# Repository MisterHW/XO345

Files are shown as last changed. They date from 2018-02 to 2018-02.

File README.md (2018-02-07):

# XO345
is a drop-in replacement for FT245 that eliminates USB in favor of a single SPI slave interface - making USB peripherals embedded peripherals without USB host and device driver. Initially developed on a MachXO2-7000HE board (hence XO245), then ported and tested with MachXO3L-1300E and MachXO3LF-6900C (renamed to XO345).

In its final implementation, a WLCSP MachXO3-1300E sits on a QFP-32 sized PCB with castellations and directly connects to the former FT245 pads. Its crystal is removed and additional signals are routed out on these pins.

PCB files will be uploaded here as well, for now please check out https://hackaday.io/project/9547-xo245

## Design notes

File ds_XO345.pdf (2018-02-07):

# XO345 SPI-Parallel Interface

FT245BL pin compatible interface controller to use USB-enabled devices with SPI

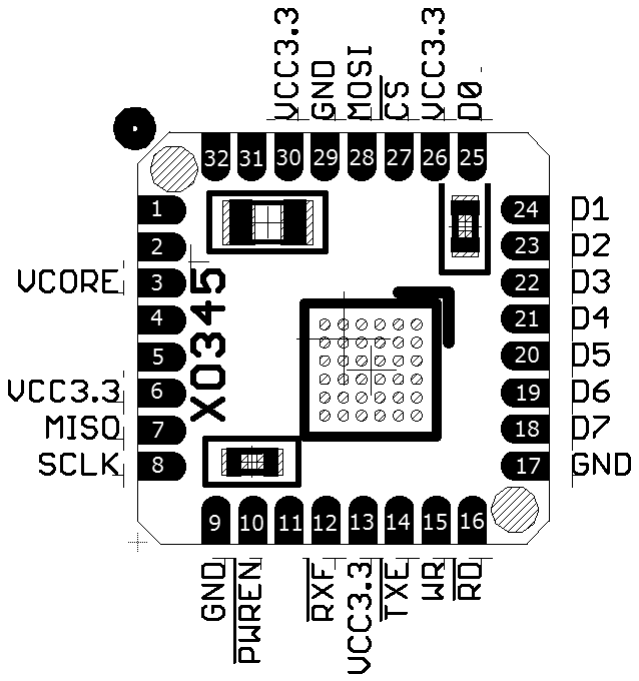
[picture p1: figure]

Features:

-QFP-32 0.8mm form factor
-drop-in replacement for FT245BL device
- on-board bypass caps
- multiple 3.3V pads
- SPI and VCORE 1.2V routed to D+,D-,XIN,XOUT and VUSB pads
- no bulky programming header
- 4-wire SPI Mode 0
up to 33 MHz
- EEPROM and control pins
connected (dev option)
- deep 256 Byte RX and
256 Byte TX buffers
- low power consumption

Description:

The XO345 is an FPGA-based FIFO interface hybrid designed as a drop-in replacement for the FTDI FT245BL chip. It has a „245“ compatible parallel interface to the target board side and provides a 4-wire MODE 0 MSB-First slave SPI as an external interface.
SPI signals and VCORE are routed to easily accessible USB and XTAL pins. While VCCIO 3.3V is supplied via pad 13, only VCORE 1.2V needs to be supplied via the existing 5V VUSB line (USB powered implementation). SPI signals are 3.3V.
Transmit and Receive buffers are 256 Byte wide, read and write timings are within 25ns of the original specs and compliant.

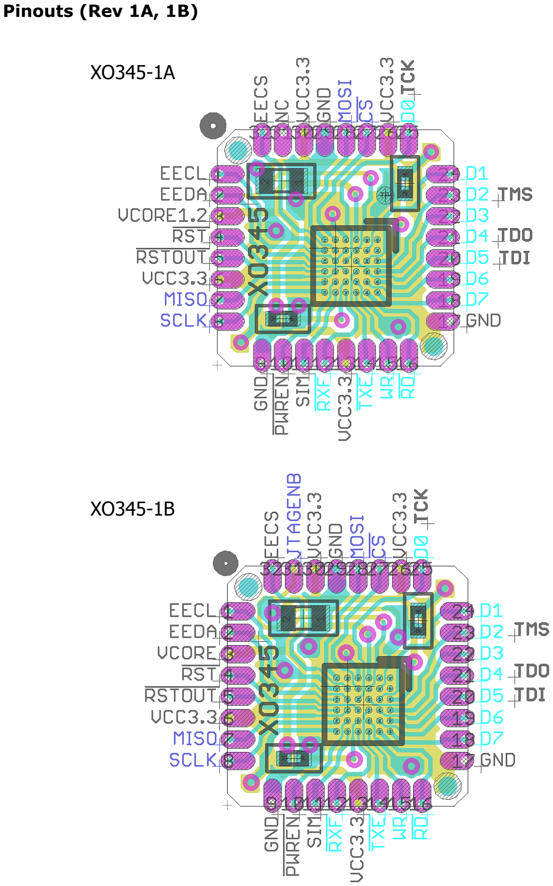
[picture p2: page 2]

Pinouts (Rev 1A, 1B)

XO345-1A

XO345-1B

Command Set

!PWREN flag [default: disabled (high)]

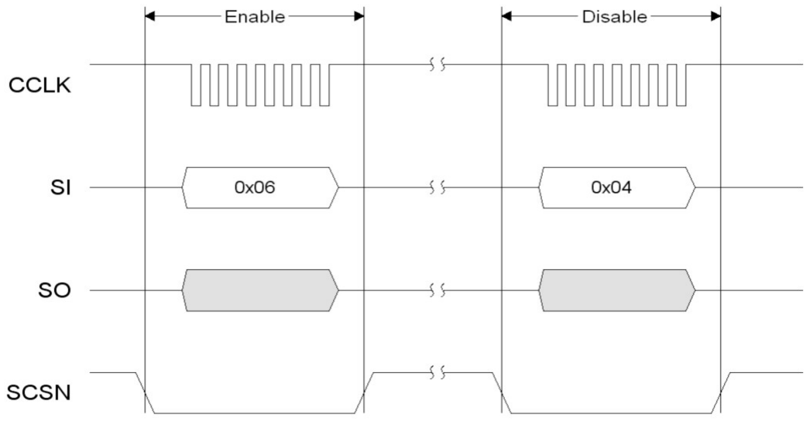
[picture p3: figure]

GPO_0 control register [default: 0x00]

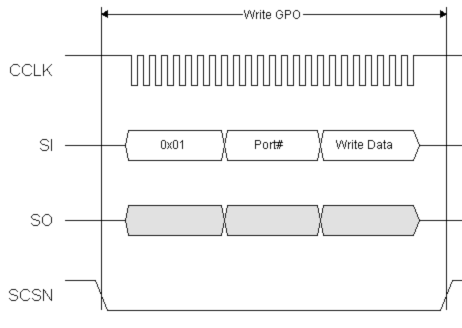
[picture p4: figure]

7 | 6 | 5 | 4 | 3 | 2 | 1 | 0
Reserved | Reserved | Reserved | Reserved | Reserved | Reserved | RXFN_STATE | RXFN_MODE

RXFN_MODE: when 0, !RXF is inhibited during write actions to the RX buffer. This simulates the bundling of bytes in a USB frame. After the write action !RXF is controlled by the level of the RX FIFO and the reaction to RDN pulses.

RXFN_STATE: (RXFN_STATE, RXFN_MODE) = 11: !RFX permanently inhibited, 01: !RXF immediately derived from the FIFO fill level and response to !RD pulses, x0: no effect

GPI_0 FIFO status register [default: 0x33]

Port#= 0x00

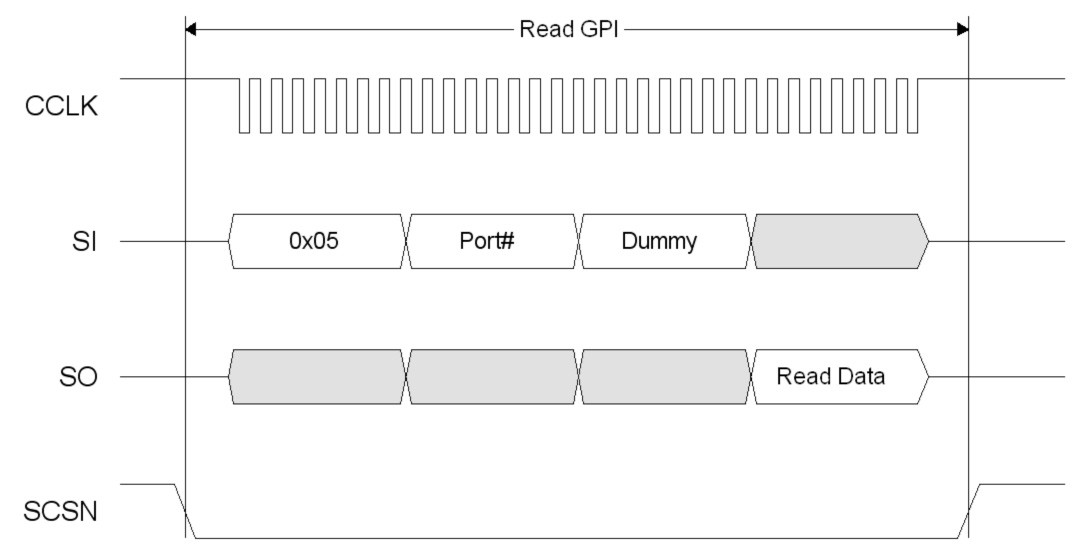
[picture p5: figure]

7 | 6 | 5 | 4 | 3 | 2 | 1 | 0
RX_FULL | RX_HI | RX_LO | RX_EMPTY | TX_FULL | TX_HI | TX_LO | TX_EMPTY

RX_FULL: RX FIFO is full at 256 Bytes (no more Bytes can be written)

RX_HI: RX FIFO is almost full (>=240 Bytes)

RX_LO: RX FIFO is not significantly filled (<= 16 Bytes)

RX_EMPTY: RX FIFO is completely empty at 0 Bytes

RX_FULL: TX FIFO is full at 256 Bytes (no more Bytes can be written)

RX_HI: TX FIFO is almost full (>=240 Bytes)

RX_LO: TX FIFO is not significantly filled (<= 16 Bytes)

RX_EMPTY: TX FIFO is completely empty at 0 Bytes

GPI_1 status register [reserved]

Port#= 0x01

7 | 6 | 5 | 4 | 3 | 2 | 1 | 0
Reserved | Reserved | Reserved | Reserved | Reserved | Reserved | Reserved | Reserved

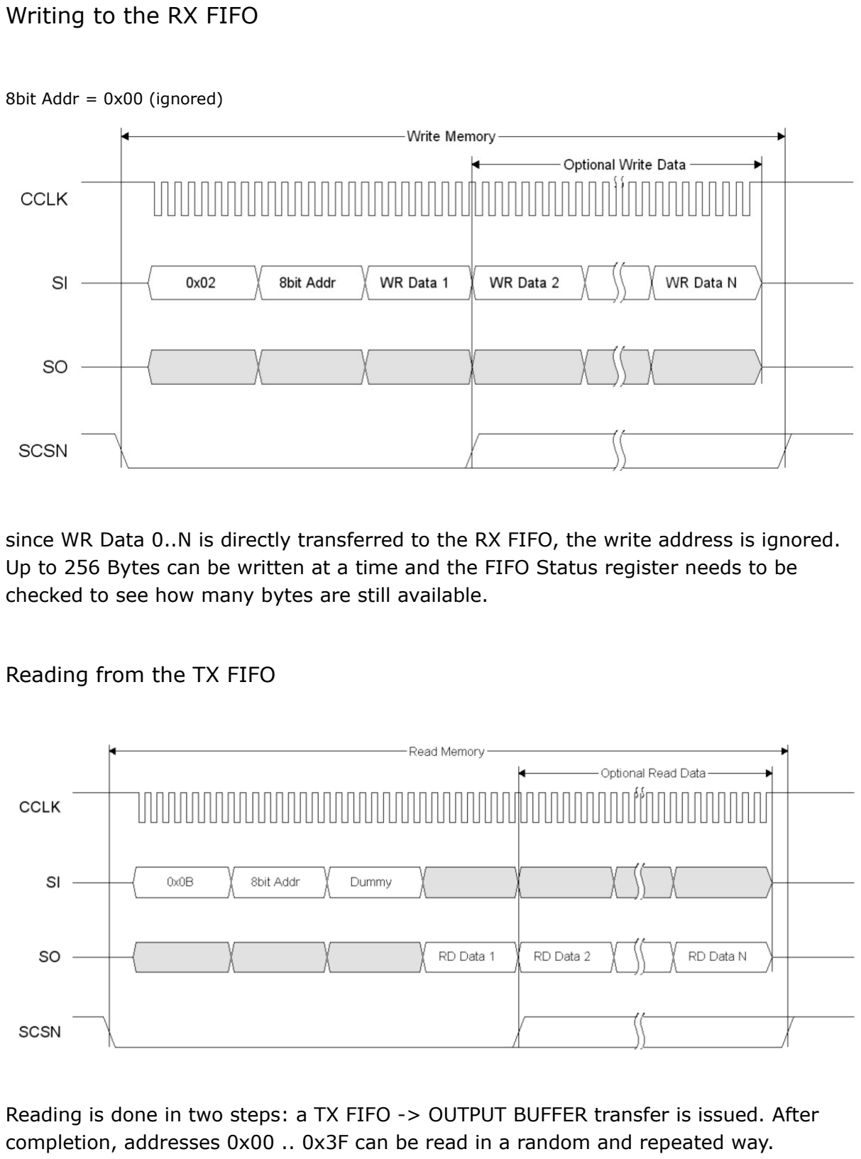
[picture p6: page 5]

Writing to the RX FIFO

8bit Addr = 0x00 (ignored)

since WR Data 0..N is directly transferred to the RX FIFO, the write address is ignored. Up to 256 Bytes can be written at a time and the FIFO Status register needs to be checked to see how many bytes are still available.

Reading from the TX FIFO

Reading is done in two steps: a TX FIFO -> OUTPUT BUFFER transfer is issued. After completion, addresses 0x00 .. 0x3F can be read in a random and repeated way.

Initiating TX FIFO -> OUTPUT BUFFER transfer

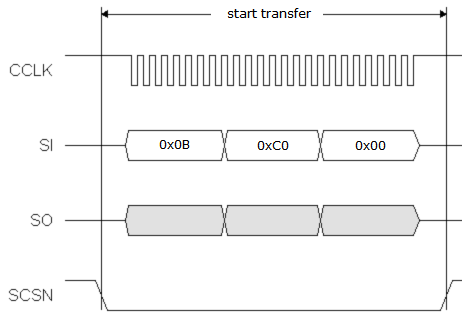
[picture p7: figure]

The transfer process is started by reading from address 0xC0. It completes within 2.5µs. Reading 0x00 yields a status byte of the OUTPUT BUFFER memory. Data can be read from addresses 0x01 .. 0x3F.

MEM(0x00): when 0x00, no valid data is inthe OUTPUT BUFFER memory. MEM(0x00): when 0xFF, the transfer is ongoing.
MEM(0x00): when 0x01.. 0x3F, that number of Bytes can be read starting at 0x01.

Device Programming

XO345 is based on the Lattice MachXO3-1300E and is programmed via JTAG. The JTAG interface is mapped to the PARALLEL pins and accessible when the TP is grounded (Rev 1B: JTAGENB pad grounded).
During programming !TXEmpty and !RXFilled must be high level to disallow target system interference with D0..D7.

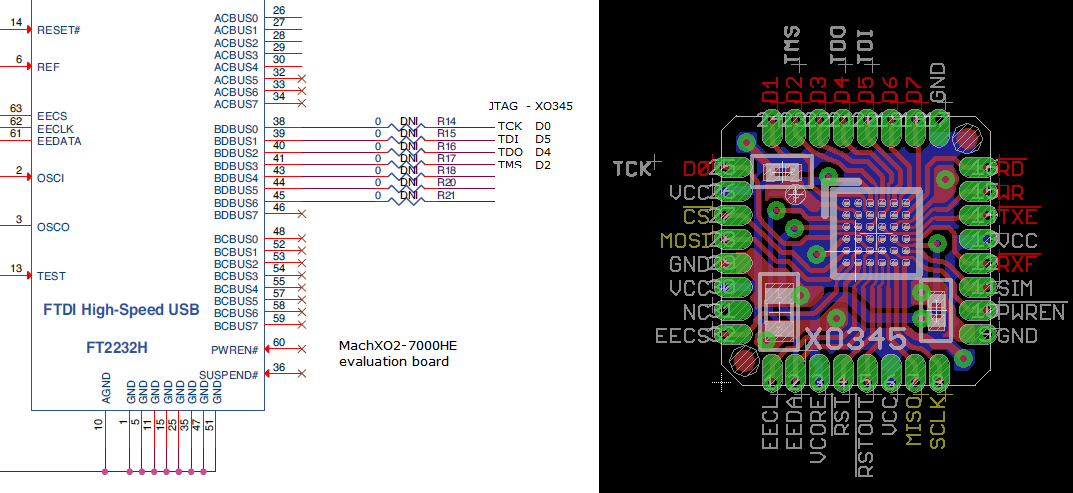
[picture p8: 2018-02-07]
XO345 hook up jtag.png

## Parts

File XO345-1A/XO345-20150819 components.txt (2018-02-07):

Stückliste exportiert aus C:/Projekte/hardware/Circuit Designs/__active__/Detektor/XO345/XO345-1A.sch am 19.08.2015 10:18

Qty Value      Device     Package Parts Description     MF                    MFG_PARTNO                MOUSER               SIZE
1   220nF/10V  CAP_0603   C0603   C2    Capacitor                                                                            0603
1   220nF/6.3V CAP_0402   C0402   C1    Capacitor       TDK                   C1005X5R1A224M050BC       810-C1005X5R1A224M   0402
1   22k 1%     RES_0402   R0402   R1    Resistor        Vishay                CRCW04022K70FKED          71-CRCW0402-2.7K-E3  0402
1   XO3-LCSP36 XO3-LCSP36 WLCSP36 IC    MachXO3-WLCSP36 Lattice Semiconductor LCMXO3L-1300E-5UWG36CTR50 842-XO3L13E5U36CTR50

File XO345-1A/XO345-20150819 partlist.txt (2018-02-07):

Partlist

Exported from XO345-1A.brd at 19.08.2015 10:17

EAGLE Version 7.3.0 Copyright (c) 1988-2015 CadSoft

Assembly variant: actual

Part     Value          Package  Library      Position (mm)         Orientation

C1       220nF/6.3V     C0402    ESP8266      (7.19 2.4)            R270
C2       220nF/10V      C0603    ESP8266      (1.95 2.35)           R270
IC       XO3-LCSP36     WLCSP36  custom-parts (5.19 5)              R0
R1       22k 1%         R0402    ESP8266      (2.04 7.05)           R0

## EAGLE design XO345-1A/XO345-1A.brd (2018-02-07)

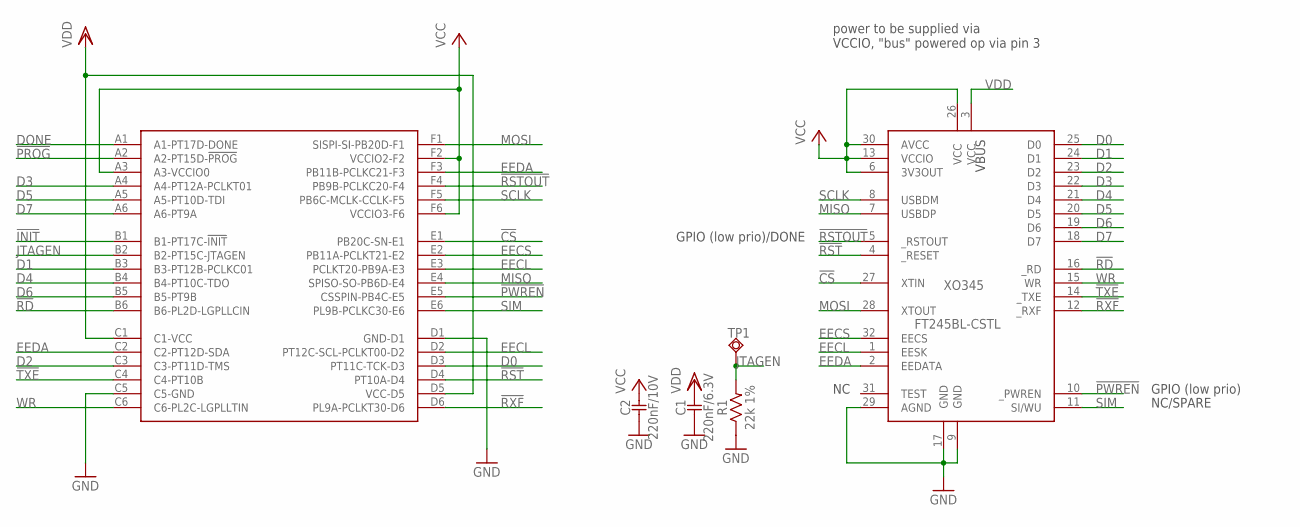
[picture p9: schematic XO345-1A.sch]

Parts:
C1: 220nF/6.3V; C0402; MFG_PARTNO C1005X5R1A224M050BC; MOUSER 810-C1005X5R1A224M
C2: 220nF/10V; C0603
IC: XO3-LCSP36; WLCSP36; MFG_PARTNO LCMXO3L-1300E-5UWG36CTR50; MOUSER 842-XO3L13E5U36CTR50
R1: 22k 1%; R0402; MFG_PARTNO CRCW04022K70FKED; MOUSER 71-CRCW0402-2.7K-E3
TP1: TPSQTP06R; TP06R
XO345: FT245BL-CSTL; LQFP-32-CAST

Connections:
!CS: IC.E1 (PB20C-SN-E1), XO345.27 (XTIN)
!INIT: IC.B1 (B1-PT17C-!INIT!)
!PROG: IC.A2 (A2-PT15D-!PROG!)
!PWREN: IC.E5 (CSSPIN-PB4C-E5), XO345.10 (_PWREN)
!RD: IC.B6 (B6-PL2D-LGPLLCIN), XO345.16 (_RD)
!RST: IC.D4 (PT10A-D4), XO345.4 (_RESET)
!RSTOUT: IC.F4 (PB9B-PCLKC20-F4), XO345.5 (_RSTOUT)
!RXF: IC.D6 (PL9A-PCLKT30-D6), XO345.12 (_RXF)
!TXE: IC.C4 (C4-PT10B), XO345.14 (_TXE)
D0: IC.D3 (PT11C-TCK-D3), XO345.25 (D0)
D1: IC.B3 (B3-PT12B-PCLKC01), XO345.24 (D1)
D2: IC.C3 (C3-PT11D-TMS), XO345.23 (D2)
D3: IC.A4 (A4-PT12A-PCLKT01), XO345.22 (D3)
D4: IC.B4 (B4-PT10C-TDO), XO345.21 (D4)
D5: IC.A5 (A5-PT10D-TDI), XO345.20 (D5)
D6: IC.B5 (B5-PT9B), XO345.19 (D6)
D7: IC.A6 (A6-PT9A), XO345.18 (D7)
DONE: IC.A1 (A1-PT17D-DONE)
EECL: IC.D2 (PT12C-SCL-PCLKT00-D2), IC.E3 (PCLKT20-PB9A-E3), XO345.1 (EESK)
EECS: IC.E2 (PB11A-PCLKT21-E2), XO345.32 (EECS)
EEDA: IC.C2 (C2-PT12D-SDA), IC.F3 (PB11B-PCLKC21-F3), XO345.2 (EEDATA)
GND: C1.1, C2.1, IC.C5 (C5-GND), IC.D1 (GND-D1), R1.1, XO345.9 (GND), XO345.17 (GND), XO345.29 (AGND)
JTAGEN: IC.B2 (B2-PT15C-JTAGEN), R1.2, TP1.TP
MISO: IC.E4 (SPISO-SO-PB6D-E4), XO345.7 (USBDP)
MOSI: IC.F1 (SISPI-SI-PB20D-F1), XO345.28 (XTOUT)
SCLK: IC.F5 (PB6C-MCLK-CCLK-F5), XO345.8 (USBDM)
SIM: IC.E6 (PL9B-PCLKC30-E6), XO345.11 (SI/WU)
VCC: C2.2, IC.A3 (A3-VCCIO0), IC.F2 (VCCIO2-F2), IC.F6 (VCCIO3-F6), XO345.6 (3V3OUT), XO345.13 (VCCIO), XO345.26 (VCC), XO345.30 (AVCC)
VDD: C1.2, IC.C1 (C1-VCC), IC.D5 (VCC-D5), XO345.3 (VCC)
WR: IC.C6 (C6-PL2C-LGPLLTIN), XO345.15 (WR)

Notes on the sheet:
power to be supplied via VCCIO, "bus" powered op via pin 3
VBUS
NC/SPARE
GPIO (low prio)
GPIO (low prio)/DONE

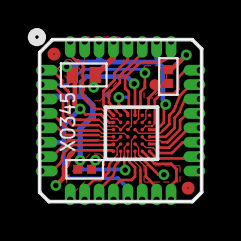
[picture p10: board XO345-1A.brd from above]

Board: 2 copper layers, 9.0 x 9.0 mm, 6 parts (0 on the bottom side), 27 nets.

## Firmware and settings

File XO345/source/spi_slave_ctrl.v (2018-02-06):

// --------------------------------------------------------------------
// >>>>>>>>>>>>>>>>>>>>>>>>> COPYRIGHT NOTICE <<<<<<<<<<<<<<<<<<<<<<<<<
// --------------------------------------------------------------------
// Copyright (c) 2010 by Lattice Semiconductor Corporation
// --------------------------------------------------------------------
//
// Permission:
//
//   Lattice Semiconductor grants permission to use this code for use
//   in synthesis for any Lattice programmable logic product.  Other
//   use of this code, including the selling or duplication of any
//   portion is strictly prohibited.
//
// Disclaimer:
//
//   This VHDL or Verilog source code is intended as a design reference
//   which illustrates how these types of functions can be implemented.
//   It is the user's responsibility to verify their design for
//   consistency and functionality through the use of formal
//   verification methods.  Lattice Semiconductor provides no warranty
//   regarding the use or functionality of this code.
//
// --------------------------------------------------------------------
//           
//                     Lattice Semiconductor Corporation
//                     5555 NE Moore Court
//                     Hillsboro, OR 97214
//                     U.S.A
//
//                     TEL: 1-800-Lattice (USA and Canada)
//                          503-268-8001 (other locations)
//
//                     web: http://www.latticesemi.com/
//                     email: techsupport@latticesemi.com
//
// --------------------------------------------------------------------
//
//  Project:           SPI slave with EFB
//  File:              main_ctrl.v
//  Title:             main_ctrl
//  Description:       Main control module of this reference design for XO2 architecture
//
// --------------------------------------------------------------------
// Code Revision History :
// --------------------------------------------------------------------
// Ver: | Author   | Mod. Date  | Changes Made:
// V1.0 | H.C.     | 2012-03-09 | Initial Release
//
// --------------------------------------------------------------------

`timescale 1 ns/ 1 ps

module main_ctrl #(parameter GPI_PORT_NUM = 2,           // GPI port number          
                   parameter GPI_DATA_WIDTH = 8,         // GPI data width           
                   parameter GPO_PORT_NUM = 1,           // GPO port number          
                   parameter GPO_DATA_WIDTH = 8,         // GPO data width           
                   parameter MEM_ADDR_WIDTH = 8,         // Memory addrss width      
                   parameter IRQ_NUM = 4,                // Interrupt request number 
                   parameter REVISION_ID = 8'h01,        // Revision ID             
                   parameter MAX_MEM_BURST_NUM = 8       // Maximum memory burst number
                   )                                     
   (                                                     
    input  wire                            clk,          // System clock
    input  wire                            rst_n,        // System reset
    input  wire                            spi_csn,      // Hard SPI chip-select (active low)
    output reg  [7:0]                      address,      // Local address for the WISHBONE interface
    output reg                             wr_en,        // Local write enable for the WISHBONE interface
    output reg  [7:0]                      wr_data,      // Local write data for the WISHBONE interface        
    output reg                             rd_en,        // Local read enable for the WISHBONE interface          
    input  wire [7:0]                      rd_data,      // Local read data for the WISHBONE interface          
    input  wire                            wb_xfer_done, // WISHBONE transfer done    
    input  wire                            wb_xfer_req,  // WISHBONE transfer request 
    output reg                             en_port,      // Genaral purpose enable port
    output reg                             gpi_ld,       // GPI latch
    output reg                             gpio_wr,      // GPIO write (high) and read (low)
    output reg  [7:0]                      gpio_addr,    // GPIO port address                     
    output reg  [GPO_DATA_WIDTH-1:0]       gpio_dout,    // GPIO port output data bus
    input  wire [GPI_DATA_WIDTH-1:0]       gpio_din,     // GPIO port input data bus
    output reg                             mem_wr,       // Memory write (high) and read (low)
    output reg  [MEM_ADDR_WIDTH-1:0]       mem_addr,     // Memory address
    output reg  [7:0]                      mem_wdata,    // Memory write data bus
    input  wire [7:0]                      mem_rdata,    // Memory read data bus
    input  wire [IRQ_NUM-1:0]              irq_status,   // IRQ status     
    output reg  [IRQ_NUM-1:0]              irq_en,       // IRQ enable
    output reg  [IRQ_NUM-1:0]              irq_clr,      // IRQ clear
	output reg 							   mem_rd_first, // [MOD] pulses for 1 clock cycle before first write
	output reg  						   mem_rd_next,	 // [MOD] pulses for 1 clock cycle before every subsequent write
	output reg	 						   mem_wr_active // [MOD] activated upon MEM_WR address setup, cleared when spi_xfer_done causes return to IDLE
    );
    
    // The definitions for SPI EFB register address
    `define SPITXDR 8'h59
    `define SPISR   8'h5A
    `define SPIRXDR 8'h5B
    
    // The definitions for the state values of the main state machine
    `define S_IDLE      4'h0
    `define S_RXDR_RD   4'h1
    `define S_TXDR_WR   4'h2
    `define S_CMD_ST    4'h3
    `define S_CMD_LD    4'h4
    `define S_CMD_DEC   4'h5
    `define S_TXDR_WR1  4'h6
    `define S_ADDR_ST   4'h7
    `define S_ADDR_LD   4'h8
    `define S_WDATA_ST  4'h9
    `define S_DATA_WR   4'hA  
    `define S_DATA_RD   4'hB    
    `define S_RDATA_ST  4'hC
    
    // The definitions for the SPI command values of the reference design
    `define C_EN_SET     8'h06 
    `define C_EN_CLR     8'h04 
    `define C_GPO_WR     8'h01 
    `define C_GPI_LD     8'h03 
    `define C_GPI_RD     8'h05 
    `define C_MEM_WR     8'h02 
    `define C_MEM_RD     8'h0B 
    `define C_IRQ_EN_WR  8'h66 
    `define C_IRQ_EN_RD  8'h6A 
    `define C_IRQ_ST     8'h65 
    `define C_IRQ_CLR    8'h61 
    `define C_REV_ID     8'h9F 
    
    // The definitions for the slim version of the SPI command values
    `define EN_SET     4'h0  
    `define EN_CLR     4'h1    
    `define GPO_WR     4'h2  
    `define GPI_LD     4'h3  
    `define GPI_RD     4'h4  
    `define MEM_WR     4'h5  
    `define MEM_RD     4'h6    
    `define IRQ_EN_WR  4'h7   
    `define IRQ_EN_RD  4'h8
    `define IRQ_ST     4'h9  
    `define IRQ_CLR    4'hA  
    `define REV_ID     4'hB  
    `define INVALID    4'hF  
        
       
       
    reg [3:0]  main_sm;           // The state register of the main state machine
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
